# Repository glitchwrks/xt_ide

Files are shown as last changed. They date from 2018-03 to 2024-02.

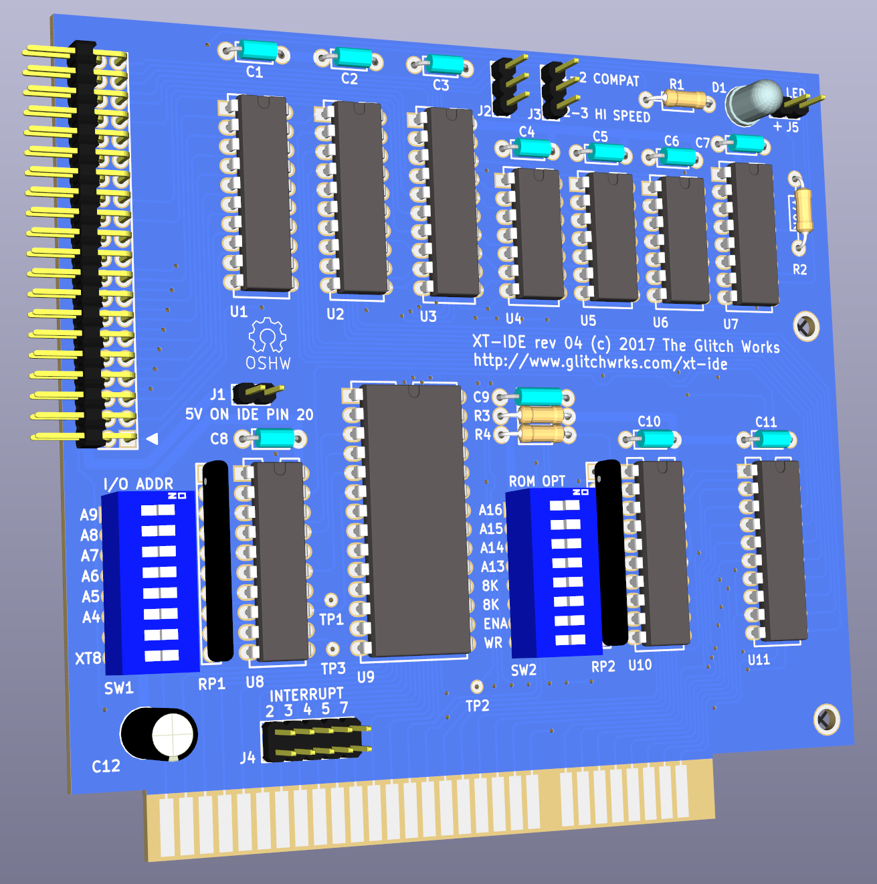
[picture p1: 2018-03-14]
gw-xtide-4-front.png

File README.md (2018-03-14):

# XT-IDE 8-Bit IDE Controller

[Glitch Works](http://www.glitchwrks.com/) continuing extension of the XT-IDE rev 2 ISA controller. This board, when used with a custom BIOS like the XT-IDE Universal BIOS, allows the use of modern 16-bit IDE devices on the 8-bit ISA bus.

More info on the Glitch Works project to provide boards, kits, and fully assembled units [can be found here](http://www.glitchwrks.com/xt-ide). A writeup on the rev 4 design process [is available here](http://www.glitchwrks.com/2017/11/23/xt-ide-rev4). 

If you're looking for the rev 3 branch, [it can be found here](https://github.com/glitchwrks/xt_ide/tree/rev_3). The README and related documentation have been preserved along with the design files.

### Jumper Settings

[modem7](http://minuszerodegrees.net/) created a great set of jumper diagrams for the rev 4 boards, available [on his site](http://www.minuszerodegrees.net/xtide/rev_4/XT-IDE%20Rev%204%20-%20general.htm).

### Bill of Materials

You can find a BOM with Mouser part numbers [here](https://github.com/glitchwrks/xt_ide/blob/master/bill_of_materials.md). Do note that you can purchase complete parts kits from [The Glitch Works](http://www.glitchwrks.com/xt-ide) in addition to bare PC boards.

### Slot 8 Support

If you want to use this card with an IBM 5160 PC/XT in Slot 8, you need a small daughterboard to make this happen. The project files for the board are available [on GitHub](https://github.com/glitchwrks/xt_ide_slot_8_support). You can find a writeup on the design and assembly process [here](http://www.glitchwrks.com/2017/02/03/slot-8-support). If you'd like to order a board, parts kit, or assembled module, see the [Glitch Works XT-IDE page](http://www.glitchwrks.com/xt-ide) for ordering information.

### Contributors

* Scott Christensen: inspriation 16-bit ATA interface for the 8-bit ISA bus
* Jeff Leyda/Hargle: original production board work, original BIOS work
* Andrew Lynch/N8VEM: layout work, initial group buy(s) on earlier revisions
* modem7: documentation, switch/jumper drawings

**Please contact me or send a pull request to get your name added to the list!**

There were no authors/contributors listed in the XT-IDE rev 2 schematics/board layout I started with. If you have contributed to this project and would like your name here, on the schematic, or on the board layout, please let me know. You can open an issue or submit a pull request.

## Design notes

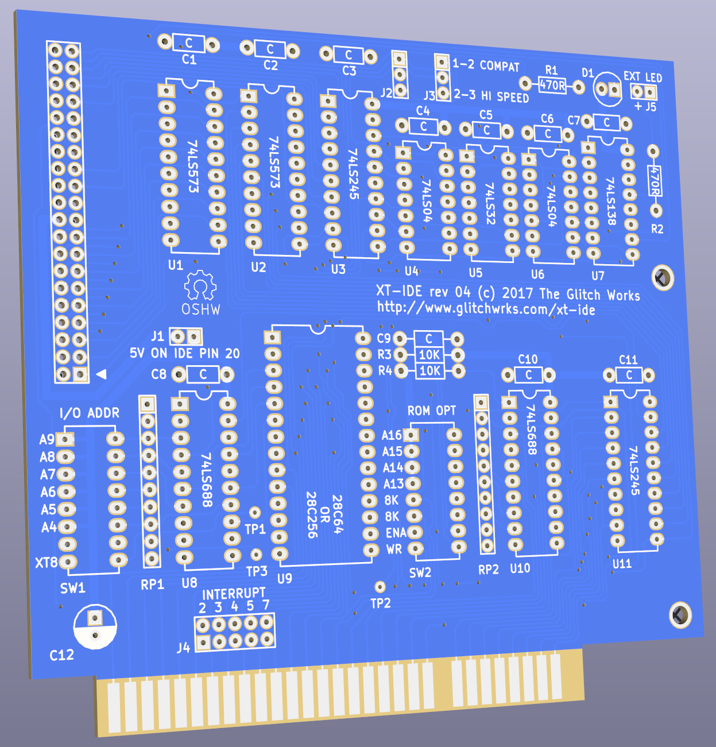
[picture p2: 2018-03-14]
gw-xtide-4-front-bare.png

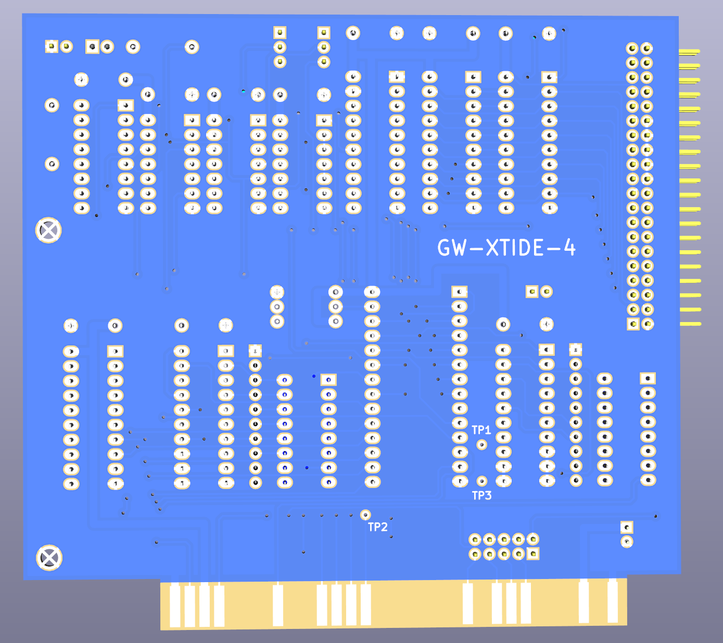
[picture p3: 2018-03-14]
gw-xtide-4-back.png

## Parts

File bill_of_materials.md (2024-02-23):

XT-IDE rev 4 Bill of Materials
------------------------------

Below is the Bill of Materials for the XT-IDE rev 4 board:

```
Ref(s)      Value                               Mouser P/N
-------------------------------------------------------------------------------
U1, U2      74F573                              595-SN74F573N
U3, U11     74LS245                             595-SN74LS245N
U4, U6      74LS04                              595-SN74LS04N
U5          74LS32                              595-SN74LS32N
U7          74LS138                             595-SN74LS138NE4
U8, U10     74LS688                             595-SN74LS688N
U9          AT28C64B                            556-AT28C64B15PU
SW1, SW2    CTS 208-8                           774-2088
RP1, RP2    10K x 9 SIP resistors               652-4610M-1LF-10K
R1, R2      470R 1/4 Watt 5%                    660-MF1/4LCT52R471J
R3, R4      10K 1/4 Watt 5%                     603-MFR-25FBF52-10K
D1          HP HLMP-3507                        630-HLMP-3507
J3, J4      2x1 header                          538-22-28-4200 (See Note 1)
J5          5x2 header                          538-22-28-4200 (See Note 1)
J1, J2      3x1 header                          538-22-28-4200 (See Note 1)
C1-C11      0.1 uF 50V axial capacitors         594-A104M15X7RF5TAA
C12         100 uF 6.3V capacitors              667-ECE-A0JKA101I
SOCKET      28 pin socket for EEPROM            575-199628 
BRACKET     Keystone 9202 ISA bracket           534-9202
SCREWS      4-40 x 1/4" machine screw           534-9301
SHUNTS      0.1" jumper shunts, 2x required     571-3828118 (See note 2)
```

Note 1: Order a 20 (or greater) breakaway header, break into the required lengths.

Note 2: additional jumper shunts are required for IDE Pin 20 power and IRQ selection. Interrupt features are not currently used so no IRQ shunt has been provided in parts kits.

Parts Kits
----------

Parts kits are available from [The Glitch Works](http://www.glitchwrks.com/xt-ide). Some substitutions will be made for the above list. The kit is a complete parts kit and includes everything you need to populate an XT-IDE rev 4 board -- you supply the solder and tools. The parts kit with a rev 4 PC board can be purchased through our Tindie store:

[https://www.tindie.com/products/10655/](https://www.tindie.com/products/10655/)

Substitutions
-------------

All 7400 series logic ICs can be substituted for LS, ALS, ACT, or HCT equivalents.

RP1, RP2, R3, and R4 are pull-up/pull-down resistors, their values are noncritical. Anything from 2.2K - 47K should be fine.
R1, R2 tolerance is not critical, but using a substantially different value will alter LED brightness. Do not use less than 220R.
C1 - C11 are power supply bypass, 0.01 - 0.1 uF axial or radial ceramic capacitors are fine.
C11 is for power supply decoupling, any value from 47 uF up is fine, aluminum electrolytic or tantalum.

SW1, SW2 are just 8 position DIP switches, use whatever is cheap/convenient.
D1 is just an indicator, use whatever you'd like

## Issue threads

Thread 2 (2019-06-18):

Feature request

johndunlap, 2019-06-18:
I'm trying to build a hardcard for my IBM 5150 using XT-IDE as the controller. There are two features which would make this considerably easier(nicer) which I hope would be easy to add.
1) 2 extra screw holes on the side opposite the existing mounting bracket. This would allow the board to be attached to a metal back plate with 4 screws instead of 2.
2) Take 12 volts off the ISA bus at B9 and add a right angle 4 pin header or mini-molex with the following pinout:

Pin | Name | Color | Description
-- | -- | -- | --
1 | +5V | Red | +5 VDC
2 | GND | Black | +5 V Ground
3 | GND | Black | +12 V Ground (Same as +5 V Ground)
4 | +12V | Yellow | +12 VDC

This would allow a 3.5" IDE spinner to be powered directly off the XT-IDE without the need for a molex connector from the power supply.

johndunlap, 2019-06-18:
With regard to #2, this feature already exists on the Monotech XT-IDE card: https://monotech.fwscart.com/XT-IDE_Bootable_8-bit_ISA_IDE_Interface_Card/p6083514_19478732.aspx

chapmajs, 2019-06-19:
Hi there, thanks for your interest in the project! The power plug was actually deleted off of the XT-IDE rev 3 boards when I reworked the rev 2 design because we determined very few people needed it. If you're wanting a hardcard workalike device, I'd recommend going with an industrial Flash module (DOM, IDE SSD). They draw significantly less power and don't put the lever strain on the ISA slot/bracket that a mechanical hardcard setup would.

I would caution against buying Monotech stuff, I've had several folks buy XT-IDEs from me after buying some of the knockoffs and having them fail after some time. That Monotech board is basically our open source XT-IDE design, just with our copyright information removed. The proliferation of these cut rate knockoffs are actually why I've stopped selling the rev 4 boards, kits, and assembled cards.

johndunlap, 2019-06-19:
I currently have a Glitchworks rev 4 XT-IDE with a 256m DOM(which I assembled from a kit). It works perfectly! I completely agree that it is difficult to beat the functionality of a DOM for the price. However, for me, being able to hear the hard drive working is part of the nostalgia of having a vintage PC. I could put a spinner into one of the drive bays but I'm trying to recreate the form factor of my first computer, which was an IBM 5150 with a 20m Quantum Hardcard and two 360k floppy drives.

As this is a feature that very few people need, it might make sense for me to add it back myself in KiCAD and having a custom board made.

chapmajs, 2019-06-19:
Absolutely! That's one of the major points of keeping this an open source community based projects: people can hack what they need onto the board if it's not something that makes sense to add to the core design! On the Vintage Computer Forums, we'd talked briefly about doing a full length ISA version with mounting holes in the FR4 circuit board for laptop sized IDE drives, though that probably won't get you the mechanical feel you want.

Feel free to fork the repository and make your changes, I'll link to them from the README and the XT-IDE page on glitchwrks.com once you've got it squared away! If you need any help on your work, don't hesitate to ask either here, or better yet ask on the VC Forums http://www.vcfed.org/forum/ which is where most of the development for these projects is discussed.

The only thing about doing a small run of boards is that to have the hard gold edge plating done properly, it'll be very expensive. You can get away with ENIG if you don't mind with having to clean the edge connector periodically -- ENIG is such a thin layer of gold (a few atoms thick) that you'll basically immediately be down to the nickel.

johndunlap, 2019-06-19:
I have a small CNC machine. Would it be possible to mill a single board or are there too many layers?

chapmajs, 2019-06-19:
I wouldn't bother trying to mill a board, it's only two layer but you'd be stuck having to either do through-hole plating at home (involved process) or soldering wires through all the vias and soldering the ICs on top and bottom (not fun). Getting a circuit board made in small quantity isn't expensive anymore, even for largeish ones, but getting one made with actual selective hard gold plating *is* still expensive.

Selective hard gold plating is the proper surface finish for edge connectors, like the ISA card edge. The wear resistance and contact life is far superior to ENIG or HASL (HASL being inappropriate for anything but prototypes). It's a two step electroplating process and most of the cheap Chinese board houses either aren't set up for it at all, or aren't set up to do it properly. You'll notice that none of the knockoff boards are using actual selective hard gold plating...

Anyway, the production XT-IDE rev 3 and 4 boards are run at PCB Cart, which is a Chinese board shop that does actually do real selective hard gold plating. They will probably be your cheapest bet if you're wanting real hard gold plating; if it's not that important from you, use pcbshopper.com and order ENIG (every one of them should be able to do ENIG for a good price).

johndunlap, 2019-06-19:
"On the Vintage Computer Forums, we'd talked briefly about doing a full length ISA version with mounting holes in the FR4 circuit board for laptop sized IDE drives"

That's actually a really cool idea!

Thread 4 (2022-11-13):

ERC errors in KiCAD

AndersBNielsen, 2022-11-13:
The schematic looks a bit interesting in KiCAD 6. Lots of unconnected pins etc. Of course I also had to remap symbols.

This is the ERC errors:

ERC report (Wednesday, 26 October 2022 at 08.41.12, Encoding UTF8)

***** Sheet /
[duplicate_reference]: Duplicate items U9A

    ; Severity: error
    @(218.44 mm, 226.06 mm): Symbol U9 [28C256-RESCUE-XT-IDE]
    @(132.08 mm, 231.14 mm): Symbol U9 [74LS688]
[duplicate_reference]: Duplicate items U6F

    ; Severity: error
    @(298.45 mm, 318.77 mm): Symbol U6F [74LS04]
    @(106.68 mm, 127.00 mm): Symbol U6 [74LS688]
[unit_value_mismatch]: Different values for U6F (74LS04) and U6A (74LS688)
    ; Severity: error
    @(298.45 mm, 318.77 mm): Symbol U6F [74LS04]
    @(106.68 mm, 127.00 mm): Symbol U6 [74LS688]
[duplicate_reference]: Duplicate items U5E

    ; Severity: error
    @(114.30 mm, 165.10 mm): Symbol U5E [74LS04]
    @(369.57 mm, 161.29 mm): Symbol U5D [74LS32]
[unit_value_mismatch]: Different values for U5E (74LS04) and U5D (74LS32)
    ; Severity: error
    @(114.30 mm, 165.10 mm): Symbol U5E [74LS04]
    @(369.57 mm, 161.29 mm): Symbol U5D [74LS32]
[different_unit_net]: Pin 11 is connected to both Net-(U5-Pad11) and Net-(U4-Pad9)
    ; Severity: error
    @(102.87 mm, 165.10 mm): Symbol U5E [74LS04] Pin 11 [, Input, Line]
    @(384.81 mm, 161.29 mm): Symbol U5D [74LS32] Pin 11 [, Output, Line]
[duplicate_reference]: Duplicate items U3A

    ; Severity: error
    @(284.48 mm, 123.19 mm): Symbol U3 [74LS245]
    @(223.52 mm, 35.56 mm): Symbol U3 [74LS573]
[multiple_net_names]: Both VCC and DMACK are attached to the same items; VCC will be used in the netlist
    ; Severity: warning
    @(218.44 mm, 201.93 mm): Symbol U9 [28C256-RESCUE-XT-IDE] Pin 28 [VCC, Power input, Line]
    @(328.93 mm, 59.69 mm): Label 'DMACK'
[pin_to_pin]: Pins of type Tri-state and Output are connected
    ; Severity: warning
    @(266.70 mm, 123.19 mm): Symbol U3 [74LS245] Pin 13 [B5, Tri-state, Line]
    @(320.04 mm, 189.23 mm): Symbol U4C [74LS04] Pin 6 [, Output, Inverted]
[pin_to_pin]: Pins of type Tri-state and Output are connected
    ; Severity: warning
    @(266.70 mm, 128.27 mm): Symbol U3 [74LS245] Pin 11 [B7, Tri-state, Line]
    @(243.84 mm, 140.97 mm): Symbol U5B [74LS04] Pin 4 [, Output, Inverted]
[pin_to_pin]: Pins of type Output and Tri-state are connected
    ; Severity: warning
    @(196.85 mm, 132.08 mm): Symbol U8B [74LS32] Pin 6 [, Output, Line]
    @(266.70 mm, 110.49 mm): Symbol U3 [74LS245] Pin 18 [B0, Tri-state, Line]
[pin_to_pin]: Pins of type Output and Tri-state are connected
    ; Severity: warning
    @(196.85 mm, 110.49 mm): Symbol U8A [74LS32] Pin 3 [, Output, Line]
    @(266.70 mm, 113.03 mm): Symbol U3 [74LS245] Pin 17 [B1, Tri-state, Line]
[no_connect_connected]: A pin with a "no connection" flag is connected
    ; Severity: warning
    @(365.76 mm, 62.23 mm): Symbol P1 [CONN_20X2] Pin 32 [P32, Passive, Inverted]
[no_connect_connected]: A pin with a "no connection" flag is connected
    ; Severity: warning
    @(365.76 mm, 64.77 mm): Symbol P1 [CONN_20X2] Pin 34 [P34, Passive, Inverted]
[multiple_net_names]: Both GND and CSEL are attached to the same items; GND will be used in the netlist
    ; Severity: warning
    @(218.44 mm, 250.19 mm): Symbol U9 [28C256-RESCUE-XT-IDE] Pin 14 [GND, Power input, Line]
    @(374.65 mm, 57.15 mm): Label 'CSEL'
[power_pin_not_driven]: Input Power pin not driven by any Output Power pins
    ; Severity: error
    @(26.67 mm, 204.47 mm): Symbol #PWR0101 [VCC] Pin 1 [VCC, Power input, Line]
[pin_not_connected]: Pin not connected
    ; Severity: error
    @(72.39 mm, 196.85 mm): Symbol RR2 [RR9] Pin 10 [10, Passive, Inverted]
[pin_not_connected]: Pin not connected
    ; Severity: error
    @(69.85 mm, 196.85 mm): Symbol RR2 [RR9] Pin 9 [9, Passive, Inverted]
[power_pin_not_driven]: Input Power pin not driven by any Output Power pins
    ; Severity: error
    @(307.34 mm, 171.45 mm): Symbol U4B [74LS04] Pin 7 [GND, Power input, Line]
[pin_not_connected]: Pin not connected
    ; Severity: error
    @(33.02 mm, 40.64 mm): Symbol BUS1 [BUSPC] Pin 9 [+12V, Passive, Line]
[pin_to_pin]: Pins of type Output and Tri-state are connected
    ; Severity: warning
    @(33.02 mm, 50.80 mm): Symbol BUS1 [BUSPC] Pin 13 [IOW, Output, Inverted]
    @(266.70 mm, 125.73 mm): Symbol U3 [74LS245] Pin 12 [B6, Tri-state, Line]
[pin_not_connected]: Pin not connected
    ; Severity: error
    @(29.21 mm, 142.24 mm): Symbol SW1 [DIPS_08] Pin 7 [, Passive, Line]
[pin_not_connected]: Pin not connected
    ; Severity: error
    @(52.07 mm, 115.57 mm): Symbol RR1 [RR9] Pin 2 [2, Passive, Inverted]
[pin_not_connected]: Pin not connected
    ; Severity: error
    @(72.39 mm, 115.57 mm): Symbol RR1 [RR9] Pin 10 [10, Passive, Inverted]
[pin_not_connected]: Pin not connected
    ; Severity: error
    @(69.85 mm, 115.57 mm): Symbol RR1 [RR9] Pin 9 [9, Passive, Inverted]
[pin_not_connected]: Pin not connected
    ; Severity: error
    @(39.37 mm, 142.24 mm): Symbol SW1 [DIPS_08] Pin 10 [, Passive, Line]

 ** ERC messages: 26  Errors 17  Warnings 9

chapmajs, 2022-11-13:
Hi there, thanks for the report! I'll try and import the project into KiCAD 6 when I get a chance.

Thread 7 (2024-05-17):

BOM is missing the IDE header

krangerich, 2024-05-17:
After I ordered parts, I noticed that there is no 40pin IDE header.

Following part could be added to the BoM:
517-30340-5002 (right angle)
517-30340-6002 (straight)

chapmajs, 2024-05-17:
Thanks for letting me know! If you like, you can fork the repo and send a PR so your name gets directly associated with the change in the commit history; otherwise, I can put it in for you with a note that you made the change.

Thanks,
Jonathan

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

krangerich, 2024-05-22:
Hey, its perfectly fine for me when you just add it without mentioning me

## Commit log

2016-05-14 Initial rev 3 commit
    [XT-IDE-B.Mask.gbs, XT-IDE-Component.gtl, XT-IDE-Copper.gbl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]
2016-05-15 Removing N8VEM from project
    [XT-IDE.kicad_pcb, XT-IDE.sch]
2016-05-25 Removing unused ISA pins, adding /CARDSEL test point
    [XT-IDE-B.Mask.gbs, XT-IDE-Component.gtl, XT-IDE-Copper.gbl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]
2016-08-22 Adding BOM
2016-08-22 Finishing BOM
2016-08-22 Adding BOM to README
2017-02-06 Adding Slot 8 Support info
2018-03-14 Flipping LED and header
    [XT-IDE.kicad_pcb, XT-IDE.sch]
2018-03-14 Minor trace routing cleanup
    [XT-IDE.kicad_pcb]
2018-03-14 Rev 4 wrapup, fixing sense on *IOR-IDE delay, adding *HI_BYTE_OUT delay
    [XT-IDE.kicad_pcb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]
2018-03-14 Updating BOM for rev 4
